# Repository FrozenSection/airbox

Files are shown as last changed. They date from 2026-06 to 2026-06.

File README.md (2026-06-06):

# AirBox

A small, self-contained indoor **environmental monitor** built on an Adafruit
QT Py ESP32-S3. It measures temperature, humidity, barometric pressure, and air
quality, and serves everything from a **local web dashboard** on local WiFi —
no cloud, no app, no Home Assistant required.

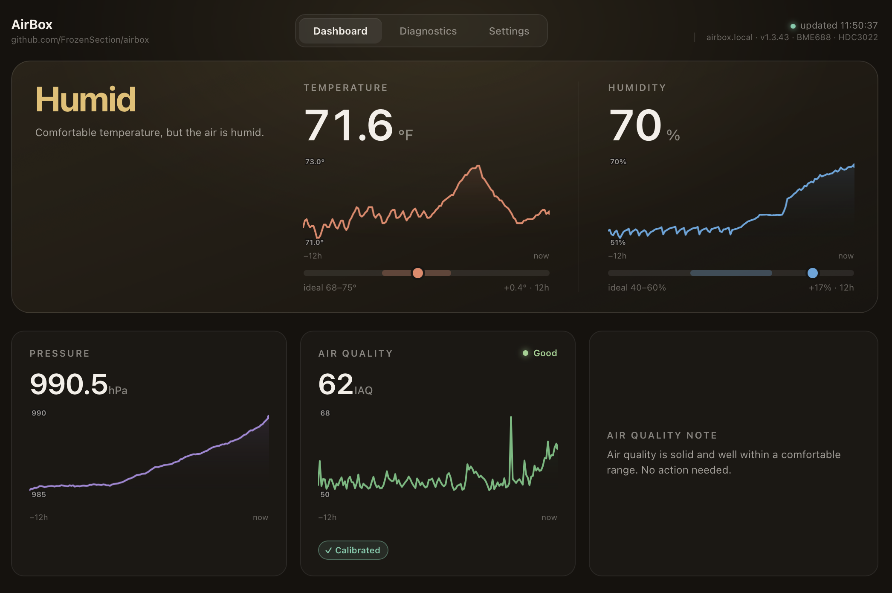
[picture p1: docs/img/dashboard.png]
dashboard placeholder

<!-- Drop a screenshot at docs/img/dashboard.png -->

## What it does

- **Measures:** temperature & humidity (HDC3022), barometric
  pressure and air quality / IAQ (BME688 via Bosch BSEC2).
- **Local dashboard:** live readings + 12 h trend charts at
  `http://airbox.local`, served straight from the device. Works on a network
  with no internet access.
- **Easy WiFi setup:** on first boot it creates a setup hotspot; scan the QR
  code on the OLED with your phone, pick your network, done.
- **Browser firmware updates:** upload new firmware from the dashboard — no
  cable, no IDE.
- **Robust by design:** hardware watchdog, automatic sensor recovery, and
  air-quality calibration that survives reboots and WiFi changes.

## Hardware

- Adafruit QT Py ESP32-S3
- Adafruit HDC3022 precision temperature/humidity sensor (STEMMA QT)
- Adafruit BME688 4-in-1 sensor (STEMMA QT)
- *Optional:* a 128×64 SSD1306 STEMMA QT OLED (enables on-device readout and
  the setup QR code; the device runs fine headless, if desired)

All three boards daisy-chain off the QT Py's STEMMA QT port (the secondary I²C
bus, `Wire1`). See [`hardware/`](hardware/) for the enclosure.

## Getting started

> **Just received a device?** The one-page
> [`docs/quick-start.md`](docs/quick-start.md) gets you from power-on to the
> dashboard in four steps.

1. **Build the firmware** — see [`firmware/README.md`](firmware/README.md) for
   the board settings and library list, then flash over USB-C.
2. **First-time WiFi setup** — [`docs/first-time-setup.md`](docs/first-time-setup.md).
3. **Using the dashboard** — what each reading means and what to trust:
   [`docs/dashboard.md`](docs/dashboard.md).
4. **Changing networks / recovery** — [`docs/recovery.md`](docs/recovery.md).
5. **Terminal / HTTP API** — drive it from `curl` or the USB serial console:
   [`docs/api.md`](docs/api.md).

## Repository layout

```
firmware/   Arduino sketch (airbox.ino, config.h, web_ui.h)
hardware/   3D-printable enclosure files + print notes
docs/        setup, dashboard, and recovery guides
```

## Licenses

- **Firmware & software:** MIT — see [`LICENSE`](LICENSE).
- **3D enclosure files:** Creative Commons Attribution 4.0 (CC BY 4.0) — see
  [`hardware/LICENSE`](hardware/LICENSE).

Contributions and remixes welcome.

## Acknowledgments

For transparency: the firmware, captive-portal provisioning, web dashboard, and documentation were **written by Anthropic's Claude** (via Claude Code), working from the requirements, design decisions, hardware testing, and review provided by the repo owner. The code is AI-written under human direction — not hand-coded by the repo owner.

(Forked from an earlier Home Assistant MQTT sensor and rebuilt as a standalone
device.)

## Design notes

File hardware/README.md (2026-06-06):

# Hardware — enclosure

3D-printable enclosure and mounting files for the standalone AirBox.

## Files

| File | Print? | Purpose |
|---|---|---|
| `enclosure/AirBox_Enclosure.STL` | ✅ ×1 | Main body — the three-chamber enclosure |
| `enclosure/AirBox_Back.STL` | ✅ ×1 | Back cover |
| `enclosure/AirBox.3MF` | — | Both parts arranged in one project file (load this if your slicer prefers it) |
| `enclosure/AirBox.STEP` | — | Editable CAD source, for remixing |

Print `AirBox_Enclosure.STL` **and** `AirBox_Back.STL` (one each). The `.3MF` is
those same two parts bundled together for convenience; the `.STEP` is the
editable source for anyone who wants to modify the design.

## Design notes / requirements

The enclosure needs to accommodate the airflow the air-quality sensor depends
on, and keep the HDC3022 and BME688 away from heat sources:

- **Three separate chambers** to isolate the HDC3022, BME688, and QT Py ESP32/OLED display
- **Vents** in all three chambers for adequate air flow and heat dissipation.
- **OLED cutout** for the 0.96" 128×64 display.
- **USB-C access** for power and recovery flashing.
- **No external BOOT button or pin-hole** — the QT Py's BOOT button (used for the
  physical WiFi reset and for DFU recovery) stays sealed inside, so reaching it
  means **opening the enclosure**. This is fine in normal use: WiFi reset and
  reconfiguration are available from the dashboard (Settings → Reconfigure WiFi),
  and firmware updates happen over the network or USB-C without opening the case.
  See [recovery](../docs/recovery.md).
- Daisy-chained STEMMA QT cables need a little internal slack.

## Print settings

| Setting | Value |
|---|---|
| Material | PETG |
| Layer height | 0.2 mm |
| Infill | Gyroid: 15% |
| Supports | _TBD per part and as needed_ |

## License

Enclosure files are licensed **CC BY 4.0** — see [LICENSE](LICENSE). (The
firmware is MIT; see the repository root.)

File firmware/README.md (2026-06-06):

# Firmware — AirBox

Arduino sketch for the Adafruit QT Py ESP32-S3 standalone environmental
monitor. Reads a BME688 (via Bosch BSEC2) and an HDC3022, serves a local web
dashboard, and provisions WiFi through a captive portal.

## Board

- **Adafruit QT Py ESP32-S3** (No PSRAM or 2MB PSRAM — both work)
- Arduino IDE board: **Tools → Board → ESP32 Arduino → Adafruit QT Py ESP32-S3**
- Install the **esp32 by Espressif Systems** board package (arduino-esp32 v3.x)
- Partition scheme: **REQUIRED → "Minimal SPIFFS (1.9MB APP with OTA/128KB
  SPIFFS)"** (Tools → Partition Scheme). This is mandatory, not optional:
  - The QT Py S3's **default partition has _no_ OTA and no usable filesystem**,
    which would silently break **browser OTA** *and* **persistent history**.
  - "Minimal SPIFFS" provides the two app slots OTA needs **and** a small
    filesystem for the saved trend history.
  - arduino-cli: append it to the FQBN —
    `…:adafruit_qtpy_esp32s3_n4r2:PartitionScheme=min_spiffs`
  - Trade-off: this replaces the TinyUF2 layout, so drag-and-drop `.uf2`
    flashing is unavailable. Flash over USB/serial (or OTA) instead.

## Libraries (Arduino IDE → Library Manager)

| Library | Author | Notes |
|---|---|---|
| Adafruit SSD1306 | Adafruit | OLED (+ Adafruit GFX, Adafruit BusIO pulled in) |
| Adafruit HDC302x | Adafruit | HDC3022 temperature/humidity |
| BSEC2 Software Library | Bosch Sensortec | BME688 air quality (`bsec2`) |
| ArduinoJson | Benoit Blanchon | v7.x |
| **ESP Async WebServer** | **ESP32Async** | the maintained fork — *not* me-no-dev |
| **Async TCP** | **ESP32Async** | matching fork; install explicitly |
| **ElegantOTA** | **Ayush Sharma** | v3.x, browser OTA |
| PubSubClient | Nick O'Leary | only if `ENABLE_MQTT` is set |

> Install the **ESP32Async** versions of ESP Async WebServer / Async TCP. The
> older `me-no-dev` packages are incompatible with arduino-esp32 v3.x. Pin the
> versions once the sketch builds cleanly.

`DNSServer`, `ESPmDNS`, `Update`, `Preferences`, `WiFi`, `Wire`, and the QR
encoder (`qrcode.h`, used for the OLED setup/URL codes) all ship with the ESP32
core — no separate install. (Don't install the ricmoo "QRCode" library — its
header name collides with the core's and would break the build.)

### ElegantOTA async mode — handled automatically

ElegantOTA must be told to use AsyncWebServer. A committed
[`airbox/build_opt.h`](airbox/build_opt.h) injects
`-DELEGANTOTA_USE_ASYNC_WEBSERVER=1` globally, which both Arduino IDE 2.x and
arduino-cli honor — so there's nothing to configure and no library files to
edit. (Verified: compiles clean on esp32:esp32 3.3.8 for the QT Py S3.)

## Build flags (`config.h`)

Everything tunable lives in [`airbox/config.h`](airbox/config.h).
No secrets are stored in committed source — WiFi credentials and optional MQTT
settings are entered in the web UI and saved to NVS; the OTA password lives in a
gitignored `secret.h` (see below).

- `ENABLE_MQTT` (default `0`) — also push to an MQTT broker / Home Assistant.
- `ENABLE_ARDUINO_OTA` (default `0`) — network flashing from the IDE/PlatformIO.
- `ENABLE_NET_OTA` (default `1`) — browser/ElegantOTA flashing. Set `0` for a
  **USB-only** build with no network flash path at all (maximum hardening).

### OTA security

The dashboard is open by design (read-only, trusted-LAN), but **network OTA is
the only remote code-execution path**, so it's locked separately. Copy
[`airbox/secret.h.example`](airbox/secret.h.example) to `airbox/secret.h` (it's
gitignored) and set a strong password:

```c
#define OTA_USERNAME "airbox"
#define OTA_PASSWORD "a-long-random-string"
```

With `secret.h` present, `/update` and the `/ota/*` endpoints require HTTP Basic
Auth — this defeats the realistic threat (an IoT worm scanning the LAN for open
ESP OTA endpoints). Without `secret.h` the build still compiles but OTA is open
and emits a `#warning`. The password is compile-time: to change it, edit
`secret.h`, recompile, and flash once over USB. (It's plain HTTP, so it doesn't
stop an on-path LAN MITM — for that you'd want signed images / Secure Boot, which
is overkill for a one-off gift.)

## First flash

1. Open `airbox/airbox.ino` in Arduino IDE.
2. Select the board + partition scheme above, install the libraries.
3. Upload over USB-C.
4. On first boot the device has no WiFi credentials → it starts the
   **AirBox-Setup** access point. Follow [docs/first-time-setup.md](../docs/first-time-setup.md).

After the first flash, firmware updates can be done entirely in the browser at
`http://<hostname>.local/update` (no cable needed).

## Building an OTA binary

The browser updater at `/update` takes a compiled **app image** (`*.ino.bin`).
Two ways to produce it:

**Arduino IDE 2.x**
1. Select the board **and** Partition Scheme **"Minimal SPIFFS (1.9MB APP with
   OTA/128KB SPIFFS)"** — this is required; a non-OTA scheme produces a binary
   that uploads but won't boot.
2. **Sketch → Export Compiled Binary** (`⌘⌥S`).
3. The binaries land in a `build/<fqbn>/` folder inside the sketch directory.
   Upload **`airbox.ino.bin`** to `/update`.
   - Do *not* use `airbox.ino.merged.bin`, `*.bootloader.bin`, or
     `*.partitions.bin` — those are for a full USB/esptool flash, not OTA.

**arduino-cli**
```sh
arduino-cli compile \
  --fqbn "esp32:esp32:adafruit_qtpy_esp32s3_n4r2:PartitionScheme=min_spiffs" \
  --output-dir build  firmware/airbox
# -> upload build/airbox.ino.bin at http://<hostname>.local/update
```
(Use `…_nopsram` instead of `…_n4r2` for the no-PSRAM board.)

Bump `FW_VERSION` in `config.h` before building so the OLED header / dashboard
confirm the new build actually took after the OTA.

## Notes on the preserved sensor core

The BSEC2 integration, CRC32-wrapped NVS calibration persistence, per-sensor
health/staleness/reinit logic, and the 60 s task watchdog are carried over
unchanged from the Home Assistant version. The watchdog is automatically
extended to 5 minutes during an OTA flash and restored afterward. BSEC
calibration (NVS namespace `bsec`) is **preserved across a WiFi reset** — only
the `cfg` namespace is cleared when you reconfigure WiFi.

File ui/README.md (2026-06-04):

# AirBox dashboard UI (source)

The dashboard the firmware serves at `http://airbox.local` lives here as editable
source, then gets bundled into the firmware.

| File | Role |
|---|---|
| `index.html` | Markup + CSS. Loads the JS via `<script src="airbox-app.js">`. |
| `airbox-app.js` | Dashboard logic (vanilla JS, canvas charts). |
| `build-web-ui.py` | Inlines the JS, **gzip-compresses** the page, and writes the `INDEX_HTML_GZ` byte array into `firmware/airbox/web_ui.h`. |

**This is the single source of truth.** `firmware/airbox/web_ui.h`'s `INDEX_HTML_GZ`
block (a gzip byte array, between the `>>> GENERATED >>>` markers) is a *generated*
artifact — don't hand-edit it; edit the files here and rebuild.

## Edit & preview
Open `index.html` directly in a browser. With no device on the network it falls
back to built-in **mock data**, so you can iterate on layout/logic offline. To
preview against a real device, serve this folder and point the fetches at the
device (or just flash and test on hardware).

## Build into the firmware
```sh
python3 ui/build-web-ui.py      # regenerates firmware/airbox/web_ui.h
```
Standard-library Python only — no packages needed. Then recompile/flash.

Notes:
- `PORTAL_HTML` (the captive-portal page) is hand-written in `web_ui.h` and is
  **not** touched by the bundler.
- The page is gzip-compressed into `INDEX_HTML_GZ` and served **zero-copy** with
  `Content-Encoding: gzip` (the `/` handler streams it straight from flash) — small
  on the wire and no per-request heap copy. The mock-data fallback only kicks in
  for `file://` preview; on the device a failed fetch shows a stale banner, never
  fake data.
- Keep it dependency-free: no CDNs, web fonts, or external libraries — the device
  serves this on a network that may have no internet.

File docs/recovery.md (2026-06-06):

# Changing networks & recovery

This device is designed so you can never paint yourself into a corner — there
are three independent ways back to a working state, from fully software to
fully physical.

## 1. It can't join WiFi (automatic)

If the saved network is gone, renamed, or has a new password, the device tries
to connect for ~30 seconds at boot and then **automatically falls back to the
`AirBox-Setup` portal**. Just redo [first-time setup](first-time-setup.md).
You don't have to do anything to trigger this.

## 2. Reconfigure from the dashboard

If want to move it to a different network:

1. Open `http://airbox.local` → **Settings** tab.
2. Tap **Reconfigure WiFi** and confirm.
3. The device reboots into the `AirBox-Setup` portal — rejoin it and pick the
   new network.

## 3. Physical reset — hold BOOT (requires opening the enclosure)

A last resort if the dashboard is unreachable *and* the device won't fall back
to the portal on its own. The BOOT button is **inside the enclosure** (no
external button or pin-hole), so this one needs you to **open the case first** —
no trouble with a couple of screws/clips, just not a no-tools step. Once it's
open:

1. With the device powered and running, **press and hold the BOOT button for
   about 3 seconds.**
2. It wipes the saved WiFi credentials and reboots into the `AirBox-Setup`
   portal.

> Press BOOT **after** the device has booted — don't hold it during power-up
> (holding it at reset puts the ESP32-S3 into USB flashing mode instead, which
> is a different thing).
>
> In practice you'll rarely get here: methods 1 and 2 above need no tools, and
> cover almost every "can't reach it" case. Reach for BOOT only when both fail.

## What is *not* erased

A WiFi reset (any of the above) clears **only the network credentials**. These
are preserved:

- The **air-quality (BSEC) calibration** — so you don't lose the 24–48 h of
  learning every time you change networks.
- Your **device name**, **temperature unit**, and **hostname** settings.

## Full wipe (start completely fresh)

To also clear the air-quality calibration, use **Settings → Recalibrate air
sensor** on the dashboard. IAQ accuracy drops to 0 and re-learns over 24–48 h.

## Updating firmware

- **Browser (normal):** Settings → **Firmware update**, or go to
  `http://airbox.local/update`. The updater asks for a login (the firmware
  update is the one password-protected action on the device); enter the
  credentials provided with the unit, then upload the new `.bin`. The device
  reboots automatically.
- **USB:** re-flash from the Arduino IDE over USB-C any time (no login needed).

If an update is ever interrupted (power loss mid-flash), the device's bootloader
keeps the previous working firmware on its other partition; power-cycle and
retry, or re-flash over USB. A normal USB re-flash needs no button presses; only
a fully unresponsive board would need manual DFU mode (hold the internal BOOT
button at power-up), which means opening the enclosure.

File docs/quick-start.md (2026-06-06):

# AirBox — Quick Start

<!--
  Regenerate the printable PDF after editing this file:

      python3 -m venv /tmp/rlvenv && /tmp/rlvenv/bin/pip install -q reportlab
      /tmp/rlvenv/bin/python docs/make-quickstart-pdf.py   # run from repo root

  NOTE: the PDF text is hardcoded in make-quickstart-pdf.py, NOT read from this
  markdown — if you change wording here, mirror it in that script too.
-->

> 🖨️ **Printable one-pager:** [`AirBox-Quick-Start.pdf`](AirBox-Quick-Start.pdf)
> (includes a scan-to-open QR for this repo). Regenerate with
> [`make-quickstart-pdf.py`](make-quickstart-pdf.py).

A standalone indoor air & environment monitor. **No app, account, or cloud** —
it serves its own dashboard on your local network.

**You'll need:** USB-C power, and a **2.4 GHz** WiFi network (name + password).

---

## 1. Power it on
Plug in USB-C. The little screen shows **WiFi Setup**, the network name
**`AirBox-Setup`**, and a **QR code**.

## 2. Join the device
On your phone, **point the camera at the QR code** → tap to join the
**`AirBox-Setup`** WiFi (it's open, no password). A setup page opens
automatically. *(If it doesn't, open a browser to `http://192.168.4.1`.)*

## 3. Hand it your WiFi
Pick your network from the list, enter its password, tap **Connect**. The device
reboots and joins your WiFi. The screen then shows its address.

## 4. Open the dashboard
On any device on the **same WiFi**, browse to:

> ## http://airbox.local

*(If `.local` doesn't resolve on your network, use the IP address shown on the
device's screen.)*

---

## Reading it
Four live tiles — **Temperature, Humidity, Pressure, Air Quality (IAQ)** — each
with a 12-hour trend chart.
- **IAQ** is a 0–500 index (lower = cleaner). It needs **24–48 h** of run time to
  self-calibrate; "calibration" climbs from 0 to 3 on the Diagnostics tab.
- **Diagnostics** tab: sensor health, network info, system stats, and a
  **Download CSV** button (last 7 days of data).
- **Settings** tab: device name, °F/°C, time zone, screen brightness & night
  mode.

## Good to know
- **Firmware updates** happen in the browser at **`http://airbox.local/update`**.
  It'll ask for a login — that's the one password-protected action on the device;
  use the update credentials provided with the unit.
- The screen dims/sleeps on a schedule if you enable **Night Mode**; the
  dashboard always works even when the screen is off.

## If something seems off
- **Can't reach `airbox.local`** → use the **IP address** shown on the screen.
- **Changing WiFi / moved it to a new network** → on the dashboard,
  **Settings → Reconfigure WiFi**, or hold the internal **BOOT** button for ~3 s
  to return to the setup screen. (Your air-quality calibration is preserved.)
- **Screen shows `STALE`** → a momentary sensor hiccup; it self-recovers, or just
  power-cycle it.

---

**Full guide, data details & source code:**
[github.com/FrozenSection/airbox](https://github.com/FrozenSection/airbox)

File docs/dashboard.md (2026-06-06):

# Using the dashboard

Open `http://airbox.local` on any device on the same WiFi network. The page has
three tabs: **Dashboard**, **Diagnostics**, **Settings**.

## Dashboard tab

### Comfort verdict
At the top, a plain-language **verdict** summarizes the room from the temperature
and humidity against your **Comfort targets** (set in Settings) — e.g.
*Comfortable, Cool, Warm, Dry, Humid, Cold & dry, Warm & humid…* — with a
one-line suggestion (e.g. "the air is dry — a humidifier would help"). The page's
accent tint shifts with it. It's an interpretation layered on top of the numbers;
the raw readings are always shown below.

### The four readings
Each with a 12-hour trend chart:

| Reading | Source | Notes |
|---|---|---|
| **Temperature** | HDC3022 | Primary, lab-grade (±0.1 °C). Shown in your chosen °F/°C. |
| **Humidity** | HDC3022 | Primary (±0.5 % RH). |
| **Pressure** | BME688 | Barometric pressure (hPa). Good for spotting weather trends. |
| **Air Quality (IAQ)** | BME688 + BSEC2 | 0 = excellent … 500 = very poor. See calibration note below. |

The **Temperature** and **Humidity** tiles also show a **range bar** marking where
the current value sits within your ideal band (`ideal X–Y`).

Charts show the most recent **~12 hours** (a sample every 5 minutes) with a time
axis (`-Xh … now`) and **min/max scale labels** so you can read the actual range
at a glance. History is saved to flash, so it **survives a reboot** and keeps up
to **7 days** for CSV export (Diagnostics tab).

> **A note on sudden steps in the trend.** Each chart point is a snapshot taken
> every 5 minutes, so a *fast* real-world change — opening a window, cooking, a
> shower in the next room — can appear as a steep, near-vertical step at the right
> edge rather than a smooth curve. That's expected: the chart is a 5-minute-
> resolution **trend**, and it simply has no in-between points to draw a fast
> event with. The big numbers at the top of each tile are the live reading (they
> update every few seconds); the chart will catch up and smooth out as the next
> few samples come in. Nothing is wrong with the sensor.

## Diagnostics tab

The raw/secondary values and device health, grouped by subsystem:

- **Sensors** — each sensor's status (OK/fault), seconds since its last good
  reading, and the BME688's **calibration** state (0–3).
- **Air quality detail** — **raw BME688 temperature / humidity** (these read a
  bit high because the gas heater warms the chip — trust the HDC3022 on the
  Dashboard for ambient T/RH), plus **eCO₂ / bVOC**, which are BSEC2 *estimates*
  from the same gas signal as IAQ (they track IAQ rather than adding independent
  info).
- **Network** — IP address, hostname, WiFi SSID, signal strength (RSSI).
- **System** — firmware version, uptime, free heap, and **last reset reason**
  (Power-on / Brownout / Task WDT / Software / Panic — handy for diagnosing an
  unexpected restart).
- **Export data (CSV)** — **Download CSV** grabs the last 7 days at 5-minute
  spacing (timestamp, temperature, humidity, pressure, IAQ).

## Settings tab

Grouped into sections:

- **Device** — Device Name (header / OLED / browser title), Temperature Unit
  (°F/°C), mDNS Hostname (the `.local` address; applies after restart), and
  **Time Zone** (a named zone — DST is handled automatically; used for
  timestamps and the night-mode clock, synced over NTP).
- **Comfort targets** — the ideal **temperature** and **humidity** bands that
  drive the verdict and range bars, entered in your chosen unit. Applies on save.
- **Display** — **Brightness** (Low / Medium / High / Max OLED contrast; lower
  meaningfully extends panel life, default Medium) and **Night Mode** (between
  the hours you set, the OLED either **blanks** or **dims** — your choice; the
  sub-options grey out when it's off). The dashboard and sensors keep running
  even while the screen is dark.
- **Maintenance** — Firmware update (browser OTA), Recalibrate air sensor
  (clears the BSEC baseline → IAQ accuracy 0), Reconfigure WiFi, Restart (the
  last two: see [recovery.md](recovery.md)).

## About IAQ calibration

The **calibration** indicator (Diagnostics tab) climbs from *unreliable* → *low*
→ *medium* → *high* over the first 24–48 hours as BSEC2 learns your environment's
baseline. Until it reaches *medium/high*, treat IAQ as a relative trend rather
than an absolute number. The learned calibration is saved to flash and restored
on reboot, so this only happens once (unless you recalibrate).

## Air-quality reference

The IAQ tile shows the **descriptor** for the current level (with a green→red dot)
and the **Air quality note** card explains it and suggests what to do. The bands
are Bosch's BSEC IAQ classification:

| IAQ | Descriptor |
|---|---|
| 0–50 | Excellent |
| 51–100 | Good |
| 101–150 | Lightly polluted |
| 151–200 | Moderately polluted |
| 201–250 | Heavily polluted |
| 251–350 | Severely polluted |
| 351–500 | Extremely polluted |

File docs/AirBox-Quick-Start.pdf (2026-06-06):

# AirBox

## Quick Start

A standalone indoor air & environment monitor. No app, account, or cloud - it serves its own dashboard on your local network.

Scan for the full
guide & source

Set it up
1 Power it on. Plug in USB-C. The screen shows WiFi Setup, the network AirBox-Setup, and a QR code.
2 Join the device. On your phone, scan that QR to join the AirBox-Setup WiFi (open, no password). A setup page opens automatically. (If not, browse to http://192.168.4.1.)
3 Hand it your WiFi. Pick your 2.4 GHz network, enter its password, tap Connect. The device reboots and joins.
4 Open the dashboard. On any device on the same WiFi, go to http://airbox.local (or the IP shown on the screen).

Reading the dashboard
Four live tiles - Temperature, Humidity, Pressure, Air Quality (IAQ) - each with a 12-hour trend. IAQ is a 0 to 500 index (lower = cleaner) and needs 24-48 h to self-calibrate. The Diagnostics tab has sensor health, network info, and a Download CSV button (last 7 days). The Settings tab covers name, units, time zone, screen brightness / night mode.

Good to know
- Firmware updates happen in the browser at http://airbox.local/update (it asks for the update login provided with your unit).
- Enable Night Mode to blank or dim the screen on a schedule; the dashboard still works while the screen is off.

If something seems off
- Can't reach airbox.local - use the IP address shown on the device screen.
- Changing WiFi / moving it - Settings > Reconfigure WiFi, or hold the internal BOOT button ~3 s. (Air-quality calibration is preserved.)
- Screen shows STALE - a momentary sensor hiccup; it self-recovers, or power-cycle it.

Full guide, data details & source code: github.com/FrozenSection/airbox

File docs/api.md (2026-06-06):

# Terminal / HTTP API

AirBox has no login shell — it's a microcontroller — but it exposes a clean HTTP
API over WiFi plus a USB serial console. Everything the dashboard does, you can do
from a terminal with `curl`.

The data and control API is **unauthenticated by design** — a trusted-LAN
environmental monitor. Anyone on the same WiFi can read it and use the
maintenance actions (restart, recalibrate, etc.). The **one exception is OTA
firmware update**, which requires a password (see below) — it's the only path
that can change the running code, so it's locked even though the rest is open.

mDNS resolves `airbox.local`, but the resolver lags a few seconds — for scripting,
use the device's raw IP (shown on the OLED, or read `.ip` from `/api/data`).

---

## 1. Over WiFi — `curl` against the HTTP API

### Read live telemetry (JSON)

```bash
curl -s http://airbox.local/api/data | jq
```

This is the same payload the dashboard polls. Key fields:

| Field | Meaning |
|---|---|
| `temp`, `rh` | Temperature (in the configured unit) and humidity % — HDC3022 |
| `pressure` | Barometric pressure (hPa) — BME688 |
| `iaq`, `iaq_acc` | Air-quality index (0–500) and BSEC accuracy (0–3) |
| `eco2`, `bvoc` | Estimated CO₂ (ppm) and breath-VOC (ppm) — BME688 |
| `bme_temp`, `bme_rh` | BME688's own temp/RH (secondary; HDC3022 is primary) |
| `hdc_ok`, `bme_ok` | Per-sensor health flags |
| `rssi`, `ssid`, `chan` | WiFi signal (dBm), network, channel |
| `mac`, `bssid`, `ip` | Device MAC (for a DHCP reservation), connected AP/mesh node, IP |
| `uptime` | Seconds since boot |
| `heap`, `heap_min`, `heap_largest` | Free / min-ever / largest-contiguous internal RAM (bytes) |
| `psram_free` | Free PSRAM (bytes) |
| `chip_temp` | ESP32-S3 die temperature (°C) — runs warm, ~50–70 °C is normal |
| `reset_reason` | Why it last rebooted |
| `fw` | Firmware version (confirms an OTA took) |

Pull one field:

```bash
curl -s http://airbox.local/api/data | jq '.chip_temp, .rssi'
```

### Watch it live (1 Hz)

```bash
while true; do curl -s http://airbox.local/api/data \
  | jq -c '{t:.temp, rh, iaq, chip:.chip_temp, rssi}'; sleep 1; done
```

### History

```bash
curl -s http://airbox.local/api/history      | jq   # JSON, the 12 h chart window
curl -s http://airbox.local/api/history.csv  -o airbox-history.csv  # full 7 days, streamed
```

### Actions (POST)

State-changing requests require the header **`X-AirBox: 1`** (a lightweight
CSRF guard — a malicious web page can't set a custom header on a cross-origin
request, so it can't trigger these). GET/read endpoints don't need it.

```bash
H='-H X-AirBox:1'
curl $H -X POST http://airbox.local/api/restart                          # reboot
curl $H -X POST http://airbox.local/api/recalibrate                      # kick BSEC recalibration
curl $H -X POST http://airbox.local/api/clear-history                    # wipe trend log only
curl $H -X POST http://airbox.local/api/factory-reset -d 'wifi=1&calib=1'
```

For `factory-reset`, each flag is optional and defaults off (`0` = keep):
- `wifi=1`  — also forget the WiFi credentials (forces re-provisioning)
- `calib=1` — also discard the BSEC calibration state

### Change settings (POST, form-encoded)

```bash
curl -H 'X-AirBox: 1' -X POST http://airbox.local/api/settings \
  -d 'name=AirBox&unit=F&hostname=airbox&brightness=64&tz=1&night_en=0'
```

Accepted fields (send only what you're changing):

`name`, `unit` (`F`/`C`), `hostname`, `brightness` (0–255), `night_en` (0/1),
`night_start`, `night_end` (minutes-of-day), `night_mode` (0=blank, 1=dim),
`tz` (timezone index), `comfort_tmin`, `comfort_tmax`, `comfort_hmin`,
`comfort_hmax`, `comfort_unit`.

Changes take effect on the next firmware loop (a flag is set; the loop applies it).

### Firmware update (OTA)

Unlike the rest of the API, **OTA requires authentication** — it's the only
endpoint that can change the firmware, so it's protected by HTTP Basic Auth
(credentials set at build time in `firmware/airbox/secret.h`). The browser
updater at `http://airbox.local/update` will prompt for them.

Scripted (ElegantOTA's two-step flow; `$OTA_USER`/`$OTA_PASS` are your
`secret.h` credentials):

```bash
IP=airbox.local; BIN=airbox.ino.bin
MD5=$(md5 -q "$BIN")                                    # Linux: md5sum
curl -u "$OTA_USER:$OTA_PASS" "http://$IP/ota/start?mode=fr&hash=$MD5"
curl -u "$OTA_USER:$OTA_PASS" -F "file=@$BIN;filename=airbox.ino.bin" \
     "http://$IP/ota/upload"                            # device reboots on success
```

(If the firmware was built with `ENABLE_NET_OTA 0`, there is no network flash
path at all — updates are USB-only.)

### Endpoint summary

| Method | Path | Purpose |
|---|---|---|
| GET  | `/` | Dashboard (gzipped HTML) |
| GET  | `/favicon.ico` | Tab icon |
| GET  | `/api/data` | Live telemetry (JSON) |
| GET  | `/api/history` | 12 h chart window (JSON) |
| GET  | `/api/history.csv` | Full 7-day history (CSV, chunked) |
| POST | `/api/settings` | Update configuration |
| POST | `/api/restart` | Reboot |
| POST | `/api/recalibrate` | Kick BSEC recalibration |
| POST | `/api/reconfigure` | Re-run first-time setup logic |
| POST | `/api/clear-history` | Wipe the trend log |
| POST | `/api/factory-reset` | Reset config (optional `wifi`/`calib` flags) |
| GET/POST | `/update`, `/ota/*` | ElegantOTA firmware upload — **auth required** |

All `POST /api/*` endpoints require the `X-AirBox: 1` header (CSRF guard); `/ota/*`
requires HTTP Basic Auth. GET endpoints are open.

A handy alias for daily use:

```bash
alias airbox='curl -s http://airbox.local/api/data | jq'
```

---

## 2. Over USB — serial console

For boot logs, the WiFi-join sequence, sensor init, and low-level diagnostics —
especially useful when WiFi won't come up and the HTTP API is unreachable.

Plug in the QT Py and open the console at **115200 baud**:

```bash
ls /dev/cu.usb*                              # find the port
screen /dev/cu.usbmodemXXXX 115200           # or: minicom -b 115200 -D <port>
```

Exit `screen` with `Ctrl-A` then `K`.

---

See also: [dashboard.md](dashboard.md) for the web UI, and
[recovery.md](recovery.md) for stuck-device procedures.

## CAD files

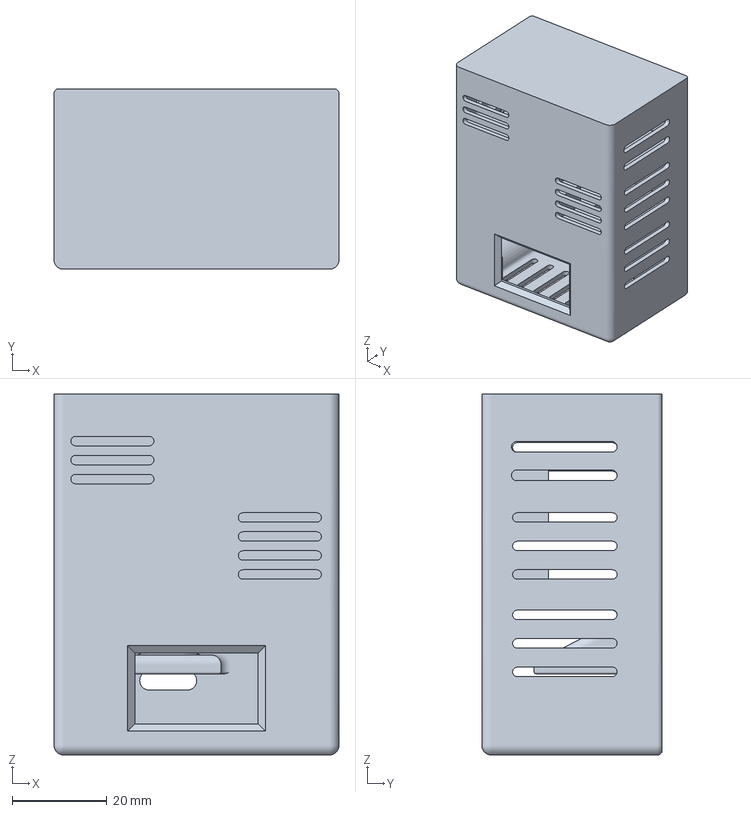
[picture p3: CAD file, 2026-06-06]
hardware/enclosure/AirBox.3MF
60.0 x 38.0 x 76.0 mm

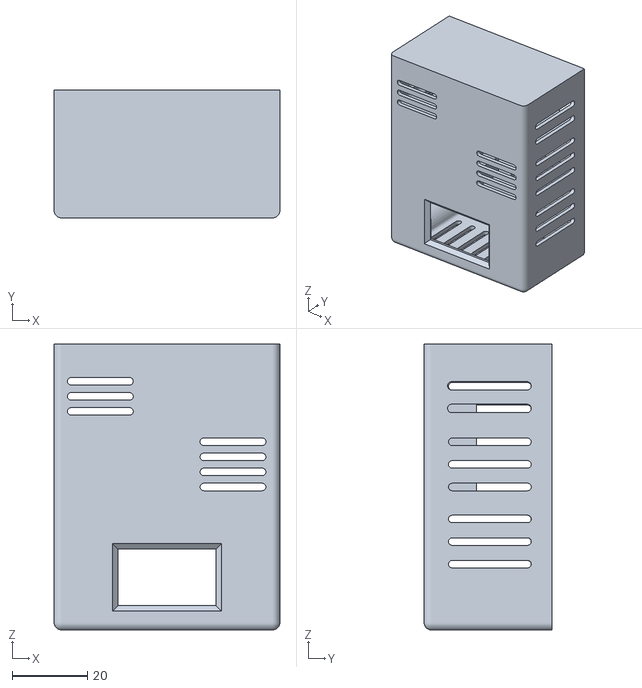
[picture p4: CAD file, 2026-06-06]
hardware/enclosure/AirBox_Enclosure.STL
60.0 x 34.0 x 76.0

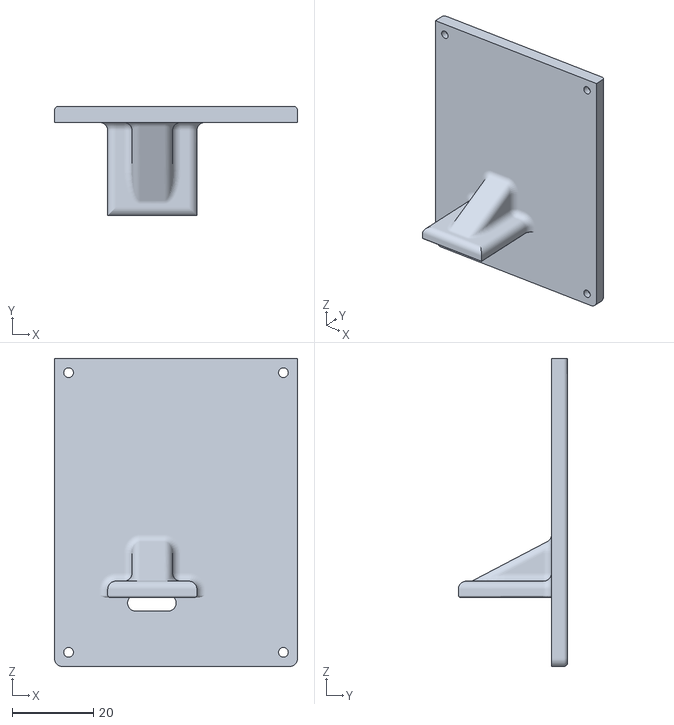
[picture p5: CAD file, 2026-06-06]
hardware/enclosure/AirBox_Back.STL
60.0 x 27.0 x 76.0

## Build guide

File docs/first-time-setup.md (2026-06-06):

# First-time setup

When the device has no saved WiFi network (fresh flash, or after a WiFi reset)
it starts a temporary setup hotspot so you can tell it which network to join.

## The quick way (with the OLED)

1. **Power the device.** After a few seconds the OLED shows **"WiFi Setup"**,
   the hotspot name **`AirBox-Setup`**, and a **QR code**.
2. **Point your phone camera at the QR code.** It offers to join the
   `AirBox-Setup` network — tap to join. 
3. Your phone should **automatically pop up the setup page**. If it doesn't,
   open a browser to **`http://192.168.4.1`**.
4. **Pick your home WiFi** from the list, type its password, tap **Connect**.
5. The device reboots and joins your network. The OLED then shows
   **"Connected!"** with the dashboard address.

## The manual way (no OLED, or QR won't scan)

1. On your phone or laptop, open WiFi settings and join the network
   **`AirBox-Setup`**.
2. A captive-portal page should appear automatically. If not, browse to
   **`http://192.168.4.1`**.
3. Select your network, enter the password, **Connect**.

## After setup

- Open the dashboard at **`http://airbox.local`** (or use the IP address your router assigned).
- Go to the **Settings** tab and:
  - set a **device name** (e.g. "Office", "Nursery" if desired),
  - choose **°F or °C**.

> **Air-quality calibration:** the IAQ reading starts at accuracy 0 and
> self-calibrates over the first **24–48 hours** of normal use. This is expected;
> see [dashboard.md](dashboard.md).

## Acceptance checklist

- [ ] Fresh boot shows the `AirBox-Setup` hotspot (and QR on the OLED).
- [ ] Phone scans the QR, joins, and the setup page appears automatically.
- [ ] Network list populates; selecting your WiFi and submitting reboots the
      device onto your network.
- [ ] `http://airbox.local` loads the dashboard; live values update.
- [ ] Trend charts begin filling in (first points appear after a few minutes).
- [ ] °F/°C toggle and device name persist across a reboot.
- [ ] Browser OTA at `/update` prompts for the update login, then flashes a new
      build, after which the device reboots on the new firmware.
- [ ] Holding **BOOT** for ~3 s returns the device to the setup portal, and the
      IAQ calibration is still intact afterward.

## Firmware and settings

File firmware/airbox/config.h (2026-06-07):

// config.h — build-time defaults and feature flags for AirBox.
//
// IMPORTANT: nothing secret lives here. WiFi credentials, the admin/OTA
// password, and (optional) MQTT credentials are all entered through the
// device's web UI at runtime and stored in NVS. This file only holds
// non-secret defaults and compile-time switches, so it is safe to commit
// to a public repository.

#ifndef CONFIG_H
#define CONFIG_H

// ----- Firmware identity -----
// Bump on every change we flash, so the OLED header / dashboard confirm which
// build is actually running (handy for verifying an OTA took).
#define FW_VERSION        "1.4.0"
#define DEVICE_MODEL      "QT Py ESP32-S3 + BME688 + HDC3022 (standalone)"

// ----- Feature flags -----
// MQTT / Home Assistant discovery. OFF by default — this is a standalone
// device. Set to 1 only if you later want to also push to an MQTT broker;
// broker host/user/pass are then entered in the web Settings page.
#define ENABLE_MQTT          0

// ArduinoOTA (network flashing from the Arduino IDE / PlatformIO / espota).
// OFF by default — browser-based OTA (ElegantOTA at /update) is the primary
// update path for a standalone gift. Turn on if you flash from a dev setup.
#define ENABLE_ARDUINO_OTA   0

// Network OTA master switch. 1 = browser/ElegantOTA flashing is available
// (default); 0 = USB-only, NO network flash path at all — the maximum-hardening
// build with zero remote code-execution surface. When enabled, OTA is protected
// by HTTP Basic Auth *if* firmware/airbox/secret.h defines OTA_USERNAME/
// OTA_PASSWORD (copy secret.h.example). Without secret.h the build still compiles
// but OTA is open and a #warning is emitted at compile time.
#define ENABLE_NET_OTA       1

// ----- Captive-portal / AP defaults -----
// Setup access point is intentionally OPEN (no password) so the OLED join-QR
// stays small enough to render crisply on the 0.96" screen, and so first-time
// setup is one scan-and-tap. The AP only ever serves the provisioning page.
#define AP_SSID           "AirBox-Setup"
#define AP_IP_STR         "192.168.4.1"

// ----- Runtime config defaults (overridable in the web Settings page) -----
#define DEFAULT_DEVICE_NAME  "AirBox"
#define DEFAULT_HOSTNAME     "airbox"        // -> http://airbox.local
#define DEFAULT_TEMP_UNIT    'F'             // 'F' or 'C'
// No admin password: the web UI (dashboard, settings, OTA at /update) is open on
// the local network by design — a trusted-LAN environmental monitor. OTA and USB
// flashing both stay available; OTA is just unauthenticated now.

// ----- Comfort targets (dashboard verdict + range bars) -----
// Stored in °C (canonical, like all temps); the web UI edits in the display
// unit and the firmware converts. Humidity is unit-agnostic %.
#define DEFAULT_COMFORT_TMIN_C  20.0f   // 68 °F
#define DEFAULT_COMFORT_TMAX_C  24.4f   // 76 °F
#define DEFAULT_COMFORT_HMIN    40
#define DEFAULT_COMFORT_HMAX    60

// ----- OLED longevity (all overridable in the web Settings page) -----
// SSD1306 contrast 0-255. Lower current = longer OLED life; the UI exposes
// Low/Medium/High/Max. A moderate default is gentler than the panel's ~0xCF.
#define DEFAULT_BRIGHTNESS   64
// Night mode: between these local hours, either fully blank the screen (saves
// the most life, keeps a bedroom dark) or just dim it. Off by default; needs
// the UTC offset for the clock.
#define DEFAULT_NIGHT_ENABLE 0
#define DEFAULT_NIGHT_START  23              // hour 0-23, local
#define DEFAULT_NIGHT_END    7
#define DEFAULT_NIGHT_MODE   0               // 0 = blank (screen off), 1 = dim
#define NIGHT_DIM_CONTRAST   4               // SSD1306 contrast used in dim mode (very low)
// Timezone is chosen from a named list (see TZ_TABLE in airbox.ino); stored as
// an index. DST is handled automatically via the POSIX TZ rule.
// 0 = UTC, 1 = Eastern (US). Default Eastern for a US-bound gift.
#define DEFAULT_TZ_INDEX     1
#define NTP_SERVER           "pool.ntp.org"
// Anti-burn-in: nudge the whole layout a few px on this cycle so static labels
// never sit on the same pixels forever.
#define PIXEL_SHIFT_INTERVAL_MS  300000UL    // 5 minutes

// ----- Trend history ring buffer -----
// Fixed 7 days at 5-minute spacing (2016 points ≈ 40 KB). Persisted to LittleFS
// so it survives a reboot, with a UTC timestamp per sample. Requires a partition
// scheme WITH a filesystem AND OTA — "Minimal SPIFFS (1.9MB APP with OTA/128KB
// SPIFFS)" (see firmware/README). The dashboard chart shows the most recent
// CHART_SAMPLES (12 h); the CSV export covers the whole 7 days.
#define HISTORY_SAMPLES          2016        // 7 days @ 5 min
#define HISTORY_INTERVAL_MS      300000UL    // 5 minutes
#define CHART_SAMPLES            144         // dashboard chart window: last 12 h (full day/night cycle)
#define HISTORY_SAVE_INTERVAL_MS 1800000UL   // flush history to flash every 30 min
#define HISTORY_FILE             "/hist.bin"

// ----- Pins / hardware -----
#define I2C_SDA_PIN       41                 // STEMMA QT (Wire1)
#define I2C_SCL_PIN       40
#define BOOT_BUTTON_PIN   0                  // QT Py BOOT button (read post-boot only)

// ----- Watchdog -----
#define WATCHDOG_TIMEOUT_MS    60000UL       // 60 s; extended to 5 min during OTA flash
#define OTA_WATCHDOG_MS        300000UL      // 5 min

// ----- Factory-reset hold -----
#define FACTORY_RESET_HOLD_MS  3000UL        // hold BOOT this long (in run/portal) to wipe WiFi

#endif // CONFIG_H

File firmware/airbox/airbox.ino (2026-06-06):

// AirBox — QT Py ESP32-S3 + BME688 (BSEC2) + HDC3022 + optional SSD1306
//
// A STANDALONE indoor environmental monitor. No Home Assistant required:
//   * WiFi is provisioned through a captive portal (OLED shows a join-QR).
//   * Data is served from a local web dashboard (live values + trend charts).
//   * Firmware updates happen in the browser (ElegantOTA at /update).
//   * mDNS publishes the dashboard at http://<hostname>.local
//
// Forked from the Home Assistant MQTT version. The hardened sensor core
// (BSEC2 + CRC32 NVS calibration, HDC3022 read path, per-sensor health /
// staleness / reinit, 60 s task watchdog) is preserved as-is. MQTT/HA
// discovery is retained behind ENABLE_MQTT (config.h), OFF by default.
//
// Recovery paths (see docs/recovery.md):
//   1. Auto-fallback to the setup portal if WiFi won't connect at boot.
//   2. Hold the BOOT button ~3 s (any time) to wipe WiFi and re-provision.
//   3. "Reconfigure WiFi" button on the dashboard.
// Calibration (NVS "bsec") is preserved across a WiFi reset.

#include "config.h"

#include <Wire.h>
#include <Adafruit_GFX.h>
#include <Adafruit_SSD1306.h>
#include <bsec2.h>
#include <Adafruit_HDC302x.h>
#include <WiFi.h>
#include <DNSServer.h>
#include <ESPmDNS.h>
#include <ArduinoJson.h>
#include <Preferences.h>
#include <esp_mac.h>
#include <esp_task_wdt.h>
#include <esp_system.h>  // esp_reset_reason()
#include <esp_heap_caps.h>  // heap_caps_get_largest_free_block() — fragmentation diag
#include <time.h>
#include <LittleFS.h>    // persistent trend history
#include "qrcode.h"  // QR encoder bundled in the ESP32 core (espressif__qrcode)

#define ELEGANTOTA_USE_ASYNC_WEBSERVER 1
#include <ESPAsyncWebServer.h>
#include <ElegantOTA.h>

#include "web_ui.h"
#include "favicon_png.h"

// Optional OTA credentials. secret.h is gitignored (see secret.h.example). If it
// defines OTA_USERNAME/OTA_PASSWORD, network OTA is protected by HTTP Basic Auth;
// if absent, OTA is open and setupElegantOTA() emits a compile-time #warning.
#if __has_include("secret.h")
  #include "secret.h"
#endif

#if ENABLE_MQTT
#include <PubSubClient.h>
#endif
#if ENABLE_ARDUINO_OTA
#include <ArduinoOTA.h>
#endif

// =================== OLED (optional) ===================
#define SCREEN_WIDTH 128
#define SCREEN_HEIGHT 64
#define OLED_RESET -1
Adafruit_SSD1306 display(SCREEN_WIDTH, SCREEN_HEIGHT, &Wire1, OLED_RESET);
bool displayOK = false;

// =================== Sensors ===================
Bsec2 envSensor;
Adafruit_HDC302x hdc;
bool bmeOK = false;
bool hdcOK = false;

const bsecSensor bsecSubscriptionList[] = {
  BSEC_OUTPUT_STATIC_IAQ,
  BSEC_OUTPUT_CO2_EQUIVALENT,
  BSEC_OUTPUT_BREATH_VOC_EQUIVALENT,
  BSEC_OUTPUT_SENSOR_HEAT_COMPENSATED_TEMPERATURE,
  BSEC_OUTPUT_RAW_TEMPERATURE,
  BSEC_OUTPUT_RAW_HUMIDITY,
  BSEC_OUTPUT_RAW_PRESSURE,
};
const uint8_t bsecSubscriptionCount =
  sizeof(bsecSubscriptionList) / sizeof(bsecSubscriptionList[0]);

Preferences bsecPrefs;
uint8_t bsecStateBlob[BSEC_MAX_STATE_BLOB_SIZE];
bool bsecStateSavedOnce = false;

struct SensorData {
  float hdcTempC, hdcRH;
  float bmeTempC, bmeRH, bmePresHpa;
  float bmeIaq, bmeEco2, bmeBvoc, bmeCompTempC;
  uint8_t bmeIaqAccuracy;
  bool hdcValid;
  bool bmeValid;
  unsigned long hdcLastGoodMs;
  unsigned long bmeLastGoodMs;
  uint16_t hdcFailStreak;
  uint16_t bmeFailStreak;
  uint32_t hdcTotalFails;
  uint32_t bmeTotalFails;
};
SensorData latest = {0, 0, 0, 0, 0, 0, 0, 0, 0, 0, false, false, 0, 0, 0, 0, 0, 0};

// Cadences
const unsigned long READ_INTERVAL_DISPLAY_MS = 3000;
const unsigned long READ_INTERVAL_HEADLESS_MS = 10000;
const unsigned long SENSOR_REINIT_INTERVAL_MS = 300000;
const unsigned long BSEC_STATE_SAVE_INTERVAL_MS = 3UL * 3600UL * 1000UL;
const unsigned long WIFI_FORCE_RECONNECT_MS = 300000;
const unsigned long MAX_VALUE_AGE_MS = 300000;
const uint16_t MAX_FAIL_STREAK = 20;

unsigned long lastRead = 0;
unsigned long lastBmeReinit = 0;
unsigned long lastHdcReinit = 0;
unsigned long lastWifiReconnect = 0;
unsigned long lastBsecStateSave = 0;
unsigned long lastHistMs = 0;

// =================== Trend history ring buffer ===================
// Static allocation (link-time accounted, no heap fragmentation). Stores raw
// values; temperature is converted to the display unit when served.
float    histT[HISTORY_SAMPLES];    // °C (raw)
float    histRH[HISTORY_SAMPLES];   // %
float    histP[HISTORY_SAMPLES];    // hPa
float    histIAQ[HISTORY_SAMPLES];  // IAQ
uint32_t histTime[HISTORY_SAMPLES]; // UTC epoch seconds (0 = before clock sync)
int histHead = 0;
int histCount = 0;
bool fsOK = false;                  // LittleFS mounted
unsigned long lastHistSave = 0;

// =================== Timezones ===================
// Named zones -> POSIX TZ rule (DST handled automatically). cfg.tzIndex stores
// the position. KEEP THIS IN SYNC with the <select id="sTz"> options in web_ui.h.
struct TzZone { const char* label; const char* posix; };
const TzZone TZ_TABLE[] = {
  {"UTC",                    "UTC0"},
  {"Eastern (New York)",     "EST5EDT,M3.2.0,M11.1.0"},
  {"Central (Chicago)",      "CST6CDT,M3.2.0,M11.1.0"},
  {"Mountain (Denver)",      "MST7MDT,M3.2.0,M11.1.0"},
  {"Arizona (no DST)",       "MST7"},
  {"Pacific (Los Angeles)",  "PST8PDT,M3.2.0,M11.1.0"},
  {"Alaska (Anchorage)",     "AKST9AKDT,M3.2.0,M11.1.0"},
  {"Hawaii (no DST)",        "HST10"},
  {"UK (London)",            "GMT0BST,M3.5.0/1,M10.5.0"},
  {"Central Europe",         "CET-1CEST,M3.5.0,M10.5.0/3"},
  {"India (Kolkata)",        "IST-5:30"},
  {"Japan (Tokyo)",          "JST-9"},
  {"Sydney",                 "AEST-10AEDT,M10.1.0,M4.1.0/3"},
};
const uint8_t TZ_COUNT = sizeof(TZ_TABLE) / sizeof(TZ_TABLE[0]);

// =================== Runtime config (NVS "cfg") ===================
struct Config {
  String ssid;
  String pass;
  String devName;
  String hostname;
  char   unit;  // 'C' or 'F'
  uint8_t brightness;   // SSD1306 contrast 0-255
  bool    nightEn;      // blank/dim the OLED on a schedule
  uint16_t nightStartMin;  // minutes-of-day 0-1439 (local)
  uint16_t nightEndMin;
  uint8_t nightMode;    // 0 = blank (off), 1 = dim
  uint8_t tzIndex;      // index into TZ_TABLE (DST-aware local time)
  float   comfortTminC, comfortTmaxC;   // comfort band, °C canonical
  uint8_t comfortHmin,  comfortHmax;    // comfort band, %
#if ENABLE_MQTT
  String mqttHost;
  String mqttUser;
  String mqttPass;
#endif
};
Config cfg;
Preferences cfgPrefs;

// =================== Web / network ===================
AsyncWebServer server(80);
DNSServer dnsServer;
String deviceId;     // qtpy_xxxxxx (from MAC)
IPAddress apIP(192, 168, 4, 1);

enum Mode { MODE_PORTAL, MODE_RUN };
Mode mode = MODE_RUN;

// Cross-task action flags. Web handlers run on the AsyncTCP task and MUST NOT
// block (no I2C / NVS / restart). They only set these flags; loop() performs
// the work on the main task.
volatile bool pendingSaveWifi = false;
volatile bool pendingSaveSettings = false;
volatile bool pendingRestart = false;
volatile bool pendingReconfigure = false;
volatile bool pendingRecalibrate = false;
volatile bool pendingWifiReset = false;   // BOOT-button WiFi wipe -> setup portal (same as Reconfigure WiFi)
volatile bool pendingClearHistory = false;   // wipe the trend ring buffer (no reboot)
volatile bool pendingFullReset = false;      // settings -> defaults (+ optional WiFi/calib), reboot
volatile bool frWifi = false, frCalib = false;

// Staging buffers for the above (written in handlers, read in loop()).
String stgSsid, stgWifiPass;
String stgName, stgUnit, stgHost;
String stgBright, stgNight, stgNStart, stgNEnd, stgNMode, stgTz;
String stgCtmin, stgCtmax, stgChmin, stgChmax, stgCunit;
#if ENABLE_MQTT
String stgMqttHost, stgMqttUser, stgMqttPass;
#endif

// =================== MQTT (optional) ===================
#if ENABLE_MQTT
WiFiClient wifiClient;
PubSubClient mqtt(wifiClient);
String haDeviceName, roomSlug, stateTopic, availTopic;
const char* DISCOVERY_PREFIX = "homeassistant";
const uint16_t MQTT_PORT = 1883;
unsigned long lastPublish = 0;
unsigned long lastMqttAttempt = 0;
const unsigned long PUBLISH_INTERVAL_MS = 30000;
const unsigned long MQTT_RETRY_MS = 5000;
#endif

static inline bool inRange(float v, float lo, float hi) {
  return !isnan(v) && !isinf(v) && v >= lo && v <= hi;
}
static inline float toUnit(float c) {
  return (cfg.unit == 'F') ? (c * 9.0f / 5.0f + 32.0f) : c;
}

// =================== Watchdog helpers ===================
void wdtReconfigure(uint32_t ms) {
  esp_task_wdt_config_t c = {.timeout_ms = ms, .idle_core_mask = 0, .trigger_panic = true};
  esp_task_wdt_reconfigure(&c);
}

// =================== Config store ===================
void loadConfig() {
  cfgPrefs.begin("cfg", true);  // read-only
  cfg.ssid      = cfgPrefs.getString("ssid", "");
  cfg.pass      = cfgPrefs.getString("pass", "");
  cfg.devName   = cfgPrefs.getString("name", DEFAULT_DEVICE_NAME);
  cfg.hostname  = cfgPrefs.getString("host", DEFAULT_HOSTNAME);
  cfg.unit      = cfgPrefs.getString("unit", String(DEFAULT_TEMP_UNIT))[0];
  cfg.brightness = cfgPrefs.getUChar("bright", DEFAULT_BRIGHTNESS);
  cfg.nightEn    = cfgPrefs.getBool("nightEn", DEFAULT_NIGHT_ENABLE);
  // Night window is stored as minutes-of-day. Migrate from the legacy hour keys
  // (nStart/nEnd) if the minute keys aren't present yet.
  cfg.nightStartMin = cfgPrefs.getUShort("nsm", (uint16_t)cfgPrefs.getUChar("nStart", DEFAULT_NIGHT_START) * 60);
  cfg.nightEndMin   = cfgPrefs.getUShort("nem", (uint16_t)cfgPrefs.getUChar("nEnd", DEFAULT_NIGHT_END) * 60);
  cfg.nightMode  = cfgPrefs.getUChar("nMode", DEFAULT_NIGHT_MODE);
  cfg.tzIndex = cfgPrefs.getUChar("tz", DEFAULT_TZ_INDEX);
  if (cfg.tzIndex >= TZ_COUNT) cfg.tzIndex = DEFAULT_TZ_INDEX;
  cfg.comfortTminC = cfgPrefs.getFloat("ctmin", DEFAULT_COMFORT_TMIN_C);
  cfg.comfortTmaxC = cfgPrefs.getFloat("ctmax", DEFAULT_COMFORT_TMAX_C);
  cfg.comfortHmin  = cfgPrefs.getUChar("chmin", DEFAULT_COMFORT_HMIN);
  cfg.comfortHmax  = cfgPrefs.getUChar("chmax", DEFAULT_COMFORT_HMAX);
#if ENABLE_MQTT
  cfg.mqttHost  = cfgPrefs.getString("mhost", "");
  cfg.mqttUser  = cfgPrefs.getString("muser", "");
  cfg.mqttPass  = cfgPrefs.getString("mpass", "");
#endif
  cfgPrefs.end();
  if (cfg.unit != 'C' && cfg.unit != 'F') cfg.unit = DEFAULT_TEMP_UNIT;
}

void saveWifiCreds(const String& ssid, const String& pass) {
  cfgPrefs.begin("cfg", false);
  cfgPrefs.putString("ssid", ssid);
  cfgPrefs.putString("pass", pass);
  cfgPrefs.end();
}

// Clears ONLY the WiFi credentials — device name, unit, and the "bsec"
// calibration namespace are preserved across a WiFi reset.
void clearWifiCreds() {
  cfgPrefs.begin("cfg", false);
  cfgPrefs.remove("ssid");
  cfgPrefs.remove("pass");
  cfgPrefs.end();
}

void setContrast(uint8_t v);     // defined with the OLED rendering helpers

// Apply the selected timezone so localtime_r() returns DST-correct local time,
// and (re)start the NTP sync.
void applyTimezone() {
  uint8_t i = (cfg.tzIndex < TZ_COUNT) ? cfg.tzIndex : 0;
  configTzTime(TZ_TABLE[i].posix, NTP_SERVER);
}

void applyAndSaveSettings() {
  if (stgName.length()) cfg.devName = stgName.substring(0, 32);
  if (stgUnit.length()) cfg.unit = stgUnit[0];
  if (stgHost.length()) {
    // Keep the mDNS hostname DNS-safe: lowercase [a-z0-9-], max 32 chars. Strips
    // anything else (spaces, punctuation, markup) rather than persisting garbage.
    String h = stgHost; h.toLowerCase(); String clean;
    for (size_t i = 0; i < h.length() && clean.length() < 32; i++) {
      char ch = h[i];
      if ((ch >= 'a' && ch <= 'z') || (ch >= '0' && ch <= '9') || ch == '-') clean += ch;
    }
    if (clean.length()) cfg.hostname = clean;
  }
  if (cfg.unit != 'C' && cfg.unit != 'F') cfg.unit = DEFAULT_TEMP_UNIT;
  if (stgBright.length()) cfg.brightness = (uint8_t)constrain(stgBright.toInt(), 0, 255);
  if (stgNight.length())  cfg.nightEn = (stgNight.toInt() != 0);
  if (stgNStart.length()) cfg.nightStartMin = (uint16_t)constrain(stgNStart.toInt(), 0, 1439);
  if (stgNEnd.length())   cfg.nightEndMin = (uint16_t)constrain(stgNEnd.toInt(), 0, 1439);
  if (stgNMode.length())  cfg.nightMode = (stgNMode.toInt() != 0) ? 1 : 0;
  if (stgTz.length()) {
    uint8_t t = (uint8_t)stgTz.toInt();
    cfg.tzIndex = (t < TZ_COUNT) ? t : 0;
  }
  // Comfort targets — temp bands arrive in comfort_unit; store canonical °C.
  if (stgCtmin.length()) cfg.comfortTminC = (stgCunit == "F") ? (stgCtmin.toFloat() - 32.0f) * 5.0f / 9.0f : stgCtmin.toFloat();
  if (stgCtmax.length()) cfg.comfortTmaxC = (stgCunit == "F") ? (stgCtmax.toFloat() - 32.0f) * 5.0f / 9.0f : stgCtmax.toFloat();
  if (stgChmin.length()) cfg.comfortHmin = (uint8_t)constrain(stgChmin.toInt(), 0, 100);
  if (stgChmax.length()) cfg.comfortHmax = (uint8_t)constrain(stgChmax.toInt(), 0, 100);
  // Sanity-clamp comfort temps to a sane indoor band (canonical °C) and ensure
  // min <= max, so a typo or an inverted/garbage range can't persist.
  cfg.comfortTminC = constrain(cfg.comfortTminC, 0.0f, 45.0f);
  cfg.comfortTmaxC = constrain(cfg.comfortTmaxC, 0.0f, 45.0f);
  if (cfg.comfortTminC > cfg.comfortTmaxC) { float t = cfg.comfortTminC; cfg.comfortTminC = cfg.comfortTmaxC; cfg.comfortTmaxC = t; }
  if (cfg.comfortHmin > cfg.comfortHmax) { uint8_t t = cfg.comfortHmin; cfg.comfortHmin = cfg.comfortHmax; cfg.comfortHmax = t; }
  cfgPrefs.begin("cfg", false);
  cfgPrefs.putString("name", cfg.devName);
  cfgPrefs.putString("unit", String(cfg.unit));
  cfgPrefs.putString("host", cfg.hostname);
  cfgPrefs.putUChar("bright", cfg.brightness);
  cfgPrefs.putBool("nightEn", cfg.nightEn);
  cfgPrefs.putUShort("nsm", cfg.nightStartMin);
  cfgPrefs.putUShort("nem", cfg.nightEndMin);
  cfgPrefs.putUChar("nMode", cfg.nightMode);
  cfgPrefs.putUChar("tz", cfg.tzIndex);
  cfgPrefs.putFloat("ctmin", cfg.comfortTminC);
  cfgPrefs.putFloat("ctmax", cfg.comfortTmaxC);
  cfgPrefs.putUChar("chmin", cfg.comfortHmin);
  cfgPrefs.putUChar("chmax", cfg.comfortHmax);
#if ENABLE_MQTT
  if (stgMqttHost.length()) cfg.mqttHost = stgMqttHost;
  if (stgMqttUser.length()) cfg.mqttUser = stgMqttUser;
  if (stgMqttPass.length()) cfg.mqttPass = stgMqttPass;
  cfgPrefs.putString("mhost", cfg.mqttHost);
  cfgPrefs.putString("muser", cfg.mqttUser);
  cfgPrefs.putString("mpass", cfg.mqttPass);
#endif
  cfgPrefs.end();
  // Apply the display + clock changes live (we're in loop() context).
  if (displayOK) setContrast(cfg.brightness);
  applyTimezone();
  Serial.println("Settings saved");
}

// =================== BSEC callback + NVS state (preserved) ===================
void bsecDataCallback(bme68x_data /*data*/, bsecOutputs outputs, Bsec2 /*bsec*/) {
  if (!outputs.nOutputs) return;
  for (uint8_t i = 0; i < outputs.nOutputs; i++) {
    const bsecData out = outputs.output[i];
    switch (out.sensor_id) {
      case BSEC_OUTPUT_STATIC_IAQ:
        latest.bmeIaq = out.signal;
        latest.bmeIaqAccuracy = out.accuracy;
        break;
      case BSEC_OUTPUT_CO2_EQUIVALENT:
        latest.bmeEco2 = out.signal;
        break;
      case BSEC_OUTPUT_BREATH_VOC_EQUIVALENT:
        latest.bmeBvoc = out.signal;
        break;
      case BSEC_OUTPUT_SENSOR_HEAT_COMPENSATED_TEMPERATURE:
        if (inRange(out.signal, -40.0f, 85.0f)) latest.bmeCompTempC = out.signal;
        break;
      case BSEC_OUTPUT_RAW_TEMPERATURE:
        if (inRange(out.signal, -40.0f, 85.0f)) latest.bmeTempC = out.signal;
        break;
      case BSEC_OUTPUT_RAW_HUMIDITY:
        if (inRange(out.signal, 0.0f, 100.0f)) latest.bmeRH = out.signal;
        break;
      case BSEC_OUTPUT_RAW_PRESSURE:
        if (inRange(out.signal, 800.0f, 1100.0f)) latest.bmePresHpa = out.signal;
        break;
      default:
        break;
    }
  }
  latest.bmeValid = true;
  latest.bmeLastGoodMs = millis();
  latest.bmeFailStreak = 0;
}

void logBsecStatus(const char* context) {
  Serial.printf("  %s — BSEC status=%d, BME68x status=%d\n",
                context, (int)envSensor.status, (int)envSensor.sensor.status);
}

static uint32_t bsecCrc32(const uint8_t* data, size_t len) {
  uint32_t crc = 0xFFFFFFFF;
  for (size_t i = 0; i < len; i++) {
    crc ^= data[i];
    for (uint8_t k = 0; k < 8; k++) crc = (crc >> 1) ^ (0xEDB88320 & -(crc & 1));
  }
  return ~crc;
}
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
void loop() {
  esp_task_wdt_reset();
#if ENABLE_NET_OTA
  ElegantOTA.loop();
#endif
  checkBootButton();
  handlePendingActions();

  if (mode == MODE_PORTAL) {
    dnsServer.processNextRequest();
    static unsigned long lastPortalDraw = 0;
    if (millis() - lastPortalDraw > 5000) { lastPortalDraw = millis(); showPortalScreen(); }
    return;
  }

  // ---- MODE_RUN ----
#if ENABLE_ARDUINO_OTA && ENABLE_NET_OTA
  ArduinoOTA.handle();
#endif

  if (bmeOK) {
    if (!envSensor.run()) {
      bool realError = ((int)envSensor.status < 0) || ((int)envSensor.sensor.status < 0);
      if (realError) {
        latest.bmeFailStreak++;
        latest.bmeTotalFails++;
        Serial.printf("BSEC run failed (streak=%u, total=%lu)\n",
                      latest.bmeFailStreak, (unsigned long)latest.bmeTotalFails);
        logBsecStatus("run");
      }
    }
  }

  // WiFi: trust auto-reconnect; force a full cycle if down too long.
  if (WiFi.status() != WL_CONNECTED) {
    if (millis() - lastWifiReconnect > WIFI_FORCE_RECONNECT_MS) {
      lastWifiReconnect = millis();
      Serial.println("WiFi still down — forcing reconnect");
      WiFi.disconnect();
      WiFi.begin(cfg.ssid.c_str(), cfg.pass.c_str());
    }
  } else {
    lastWifiReconnect = millis();
  }

#if ENABLE_MQTT
  if (!mqtt.connected() && millis() - lastMqttAttempt > MQTT_RETRY_MS) {
    lastMqttAttempt = millis();
    if (WiFi.status() == WL_CONNECTED) tryConnectMQTT();
  }
  if (mqtt.connected()) mqtt.loop();
#endif

  unsigned long now = millis();

  // Per-sensor staleness (preserved).
  bool hdcJustWentStale = false, bmeJustWentStale = false;
  if (hdcOK && latest.hdcValid && (now - latest.hdcLastGoodMs > MAX_VALUE_AGE_MS)) {
    Serial.println("HDC stale — marking offline");
    hdcOK = false; latest.hdcValid = false; hdcJustWentStale = true;
  }
  if (bmeOK && latest.bmeValid && (now - latest.bmeLastGoodMs > MAX_VALUE_AGE_MS)) {
    Serial.println("BME stale — marking offline");
    bmeOK = false; latest.bmeValid = false; bmeJustWentStale = true;
  }
  if (hdcOK && latest.hdcFailStreak > MAX_FAIL_STREAK) {
    Serial.printf("HDC failed %u reads — forcing reinit\n", latest.hdcFailStreak);
    hdcOK = false; latest.hdcValid = false; latest.hdcFailStreak = 0; hdcJustWentStale = true;
  }
  if (bmeOK && latest.bmeFailStreak > MAX_FAIL_STREAK) {
    Serial.printf("BME failed %u reads — forcing reinit\n", latest.bmeFailStreak);
    bmeOK = false; latest.bmeValid = false; latest.bmeFailStreak = 0; bmeJustWentStale = true;
  }
  bool hdcDue = (!hdcOK && (hdcJustWentStale || (now - lastHdcReinit >= SENSOR_REINIT_INTERVAL_MS)));
  bool bmeDue = (!bmeOK && (bmeJustWentStale || (now - lastBmeReinit >= SENSOR_REINIT_INTERVAL_MS)));
  if (hdcDue || bmeDue) recoverI2C();  // clear a wedged bus before re-init
  if (hdcDue) { lastHdcReinit = now; reinitHdc(); }
  if (bmeDue) { lastBmeReinit = now; reinitBme(); }

  // OLED care: night blank/dim + anti-burn-in pixel-shift.
  if (displayOK) {
    bool night = isNightNow();
    bool wasPowered = displayPowered;
    // BLANK mode powers the panel off; DIM mode keeps it on at low contrast.
    setDisplayPower(!(night && cfg.nightMode == 0));
    setContrast((night && cfg.nightMode == 1) ? NIGHT_DIM_CONTRAST : cfg.brightness);
    if (displayPowered && !wasPowered) updateRunDisplay();  // redraw on wake
    if (displayPowered && now - lastShift >= PIXEL_SHIFT_INTERVAL_MS) {
      lastShift = now;
      updateShift();
    }
  }

  unsigned long readInterval = displayOK ? READ_INTERVAL_DISPLAY_MS : READ_INTERVAL_HEADLESS_MS;
  if (now - lastRead >= readInterval) {
    lastRead = now;
    readSensors();
    updateRunDisplay();
  }

  if (now - lastHistMs >= HISTORY_INTERVAL_MS) {
    lastHistMs = now;
    recordHistory();
  }

  // Flush history to flash on a slow cadence (planned restarts flush too).
  if (fsOK && now - lastHistSave >= HISTORY_SAVE_INTERVAL_MS) {
    lastHistSave = now;
    saveHistory();
  }

#if ENABLE_MQTT
  if (now - lastPublish >= PUBLISH_INTERVAL_MS && mqtt.connected()) {
    lastPublish = now;
    publishState();
  }
#endif

  // Persist BSEC calibration once accuracy >= 1 (preserved).
  if (bmeOK && latest.bmeIaqAccuracy >= 1) {
    bool firstSave = !bsecStateSavedOnce;
    bool cadenceDue = (now - lastBsecStateSave >= BSEC_STATE_SAVE_INTERVAL_MS);
    if (firstSave || cadenceDue) {
      lastBsecStateSave = now;
      bsecStateSavedOnce = true;
      saveBsecState();
    }
  }

  // Yield the CPU briefly so the loop core can idle (WFI) between ticks instead
  // of spinning at 100%. Big steady-state heat/power cut on an always-on board;
  // the async web server runs in its own task and is unaffected, and BSEC LP
  // (3 s cadence) and the WDT (60 s) are nowhere near starved at ~100 loops/s.
  delay(10);
}

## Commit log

2026-05-29 Initial commit — standalone env-monitor (captive WiFi + local web dashboard)
    Fork of the Home Assistant env-monitor for a standalone, HA-free device.
    - Captive WiFi portal (open setup AP, OLED join-QR, network scan, reboot-to-apply)
    - Three recovery paths: auto-fallback AP, BOOT-hold WiFi wipe, dashboard reconfigure
    - Local async web dashboard: live readings, 24h trend charts, diagnostics tab,
    limited settings (name, F/C, hostname, admin password)
    - Browser OTA via ElegantOTA (password-gated, watchdog extended during flash)
    - mDNS (http://envmon.local)
    - WiFi creds + settings in NVS "cfg"; BSEC calibration ("bsec") preserved on reset
    - MQTT/HA discovery retained behind ENABLE_MQTT (off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
    [config.h, env-monitor-standalone.ino]
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2026-05-29 OLED longevity: brightness, pixel-shift jitter, NTP night-blanking
    All web-configurable from the Settings tab and persisted in NVS "cfg":
    - Display brightness (SSD1306 contrast) — Low/Medium/High/Max, default Medium;
    lower drive current is the biggest lever on panel life. Applied at boot and
    live on save.
    - Pixel-shift anti-burn-in: the run screen layout walks a small 0-2px offset
    every 5 min so static labels/divider/footer never sit on fixed pixels.
    - Night mode: blank the OLED (DISPLAYOFF) between configurable local hours via
    an NTP clock (UTC offset setting). Off by default; sensors + dashboard keep
    running while the screen is dark, and it redraws immediately on wake.
    config.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
    [airbox.ino, config.h]
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2026-05-29 Fix build: use core QR encoder, add ElegantOTA async build flag
    Verified compiling with arduino-cli (esp32:esp32 3.3.8, QT Py S3 nopsram):
    default build 59% flash / 27% RAM; MQTT+ArduinoOTA path also compiles.
    - QR: the ricmoo "QRCode" lib's qrcode.h collides with the header the ESP32
    core already bundles (espressif__qrcode, used by WiFiProv), so <qrcode.h>
    resolved to the core's. Switched drawQR() to the core's callback-based
    esp_qrcode_generate() API and dropped the external library dependency.
    - ElegantOTA: a sketch #define can't reach the library's own .cpp, so async
    mode wasn't taking. Added committed build_opt.h with
    -DELEGANTOTA_USE_ASYNC_WEBSERVER=1 (honored by Arduino IDE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
    [airbox.ino]
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2026-05-31 OLED: cleaner layout + last-reset-reason diagnostic
    Port the more readable run-screen layout from the HA env-monitor sibling:
    two divider rules / three zones, header with device name + firmware version +
    filled/hollow WiFi status dot, right-aligned (anchored) humidity, and stable
    placeholders before the first read. Char buffers avoid heap churn on redraw;
    8-point pixel-shift orbit, 2px inset so it never clips. IAQ stays numeric
    (value + accuracy) — no qualitative band, by design.
    Add esp_reset_reason() as a "Last reset" diagnostic (Power-on / Brownout /
    Task WDT / Software / Panic) on the dashboard Diagnostics tab — helps tell a
    power issue from a hang.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
    [airbox.ino]
2026-05-31 UI: right-align OLED QR codes; add Discard-changes button
    - Setup/portal + connect splash QR codes are now right-aligned (hug the right
    edge, adapting to the QR's actual size) so the left side is always free for
    text — fixes the SSID text running into the QR. Portal text lines tightened;
    splash IP moved below the QR so a long address can't collide.
    - Settings tab gains a "Discard changes" button that re-pulls the device's
    saved values into the form, throwing away unsaved edits (nothing was written),
    so you can back out cleanly without remembering the previous state.
    [airbox.ino]
2026-05-31 Persistent history (LittleFS) + CSV export; require OTA partition
    Critical: the QT Py S3 default partition (tinyuf2_noota) has no OTA slot and no
    filesystem — browser OTA and history persistence both need it. Build now
    requires "Minimal SPIFFS (1.9MB APP with OTA/128KB SPIFFS)"
    (PartitionScheme=min_spiffs). Verified compiling/flashing at 66% of the 1.9MB
    app slot.
    - Trend history persists to LittleFS (/hist.bin): saved every 30 min and before
    any planned restart, restored on boot — charts survive reboot/power-cycle.
    - Each sample now carries a UTC timestamp (from NTP) for the CSV.
    - New GET /api/history.csv: all data by default, optional ?from=&to= (UTC epoch)
    date range; timestamps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
    [airbox.ino, config.h]
2026-05-31 v1.1.0: selectable history window (24h/1wk/1mo/1yr); start versioning
    - Fixed 720-point history buffer; sample spacing = chosen window / 720, so
    storage/RAM/payload are bounded regardless of window (can't run out of space).
    Settings dropdown: 24h / 1 week / 1 month / 1 year. Changing it clears past
    data and refills at the new cadence (timestamps make this clean).
    - CSV export simplified to "Download CSV" (the retained window); the /api/
    history.csv from/to params remain for power users.
    - Bump FW_VERSION 1.0.0 -> 1.1.0. From here, bump on every flashed change so the
    OLED header / dashboard confirm which build is running (verifies an OTA took).
    Built but intentionally NOT USB-flash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
    [airbox.ino, config.h]
2026-05-31 v1.2.0: 7-day CSV + fixed 24h chart + timezone picker
    - History is now a fixed 7-day buffer at 5-min spacing (2016 pts). The dashboard
    chart shows the most recent 24h (CHART_SAMPLES); the CSV exports the full 7
    days. Removes the v1.1.0 retention-window setting and the derived-interval
    machinery — both are now fixed.
    - CSV download is explicit: button "Download CSV (7 days)", filename
    airbox-history-7d.csv; dropped the from/to range params.
    - Replace the raw UTC-offset field with a named-timezone dropdown (TZ_TABLE,
    POSIX rules) — DST handled automatically via configTzTime(). Keep the HTML
    <select> in sync with TZ_TABLE order.
    - Bump 1.1.0 -> 1.2.0. Built for OTA; not USB-flas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
    [airbox.ino, config.h]
2026-05-31 v1.2.1: bigger 2-line OLED + stale alert, I2C recovery, graph legibility, EST default
    - OLED redesigned for legibility: two large (size-2) rows — temperature+humidity,
    then pressure+IAQ (big numbers, small hPa/IAQ labels). Accuracy moved to the
    web UI only. On a sensor stall the line shows "--", the status dot goes hollow,
    and the header shows "STALE" — visible on-device without opening the dashboard.
    - I2C bus recovery (recoverI2C): clocks SCL to free a wedged SDA + STOP, then
    re-inits Wire1. Runs on boot and before each sensor reinit, so a soft reboot
    (e.g. OTA) that leaves the bus stuck can self-heal.
    - Graph legibility: charts no longer zoom tighter than a per-metric minimu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
    [airbox.ino, config.h]
2026-05-31 v1.2.2: chart time axis (span-aware, sparse-friendly)
    Each trend chart gets an x-axis: "-<span> ... now" in the bottom corners. Points
    still fill the full width; the left label shows the ACTUAL span of data present
    (e.g. -15m early on, growing to -24h once full), so it reads correctly without
    looking empty while the buffer populates. Value min/max labels stay on the left.
    [config.h]
2026-05-31 v1.2.3: settings redesign, adaptive IAQ label, drop post-connect QR
    - Settings tab reorganized into labeled cards (Device / Display / Security /
    MQTT / Save / Maintenance). Night Mode capitalized; its behavior + hours are
    now an indented, left-bordered sub-block that greys out and disables when the
    checkbox is off. Timezone moved under Device.
    - OLED: IAQ label is adaptive — "IAQ" normally, "AQ" when the row is tight
    (4-digit pressure + 3-digit IAQ), dropped only if even that won't fit — so it
    can never collide with "hPa". Font is monospace, so this is digit-count based.
    - Post-connect splash no longer shows the dashboard QR (WiFi is already set on a
    reboot/OTA); the QR stays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
    [airbox.ino, config.h]
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2026-05-31 v1.2.4: fix hidden-tab charts, group Diagnostics, settings label polish
    - Fix charts not rendering when returning to the Dashboard tab: a 60s redraw
    firing while the tab was hidden drew the canvases at 0x0. Now draw() bails on a
    zero-size canvas, and switching to the Dashboard tab forces a redraw.
    - Diagnostics reorganized into subsystem cards an EE can scan: Sensors (status +
    age + BME calibration), Air quality detail (raw BME T/RH, eCO2, bVOC), Network
    (IP, hostname, SSID, RSSI), System (firmware, uptime, heap, last reset). Added
    IP + SSID to /api/data.
    - Settings labels to Title Case (Device Name, Temperature Unit, mDNS Hostname,
    Time Zone, Admin Password); night-mode hours re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
    [airbox.ino, config.h]
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2026-06-01 v1.3.0: new Ambient dashboard + comfort targets; UI source + bundler
    New web dashboard (the "Ambient" redesign): self-contained (no CDN/fonts/libs),
    canvas charts with area fill, comfort verdict + range bars, regrouped
    diagnostics. Same API as before plus user-tunable comfort targets.
    Firmware (additive only): Config gains comfortTminC/TmaxC + comfortHmin/Hmax;
    loadConfig/applyAndSaveSettings persist them (NVS, canonical °C, converted from
    the UI's display unit); /api/settings stages comfort_*; buildDataJson emits a
    "comfort" object in display units. config.h adds DEFAULT_COMFORT_*. OLED is
    unchanged (raw values, no verdict).
    UI workflow: dashboard source now lives in ui/ (index.html + ai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
    [airbox.ino, config.h]
2026-06-01 v1.3.1: right-justify the Air Quality status pill
    The support tiles (Pressure, Air Quality) didn't inherit the flex
    space-between that the metric tiles use, so the IAQ status pill (dot + word)
    sat inline next to the label instead of at the right edge. Add `.scard .top`
    flex rule. Pressure (no pill) is unaffected. Regenerated web_ui.h from ui/.
    [config.h]
2026-06-01 v1.3.2: more chart variability (less aggressive y-axis normalization)
    The minSpan floor + 18% padding were over-flattening real 24h data. Halve the
    minSpans (temp 2->1, humidity 6->3, pressure 4->2, IAQ 25->12) and cut padding
    to 10%, so charts zoom closer to the actual range while keeping a small floor so
    sensor noise isn't amplified into fake swings.
    [config.h]
2026-06-01 v1.3.3: dynamic chart time axis + 5% padding, lower minSpan
    - Restore the dynamic left axis label (regressed in the Ambient redesign, which
    hardcoded "-24h"): it now shows the actual data span (-15m -> -24h as the
    window fills). Tag the 4 left-axis spans .axL; redraw() sets them from
    HIST length x interval.
    - Chart padding 10% -> 5%; minSpans lowered (temp 1->0.7, humidity 3->2,
    pressure 2->1.5, IAQ 12->8) for a bit more variability.
    [config.h]
2026-06-01 v1.3.4: 7-band IAQ descriptors + per-level guidance, whole-number IAQ
    Replace the 4-band pill + single templated note with Bosch's BSEC IAQ
    classification (Excellent / Good / Lightly / Moderately / Heavily / Severely /
    Extremely polluted). The tile pill shows the descriptor with a green->red ramp
    dot; the "Air quality note" card shows level-specific guidance. IAQ reports as a
    whole number (no more 113.2951 in prose). When accuracy is 0 (unreliable) the
    note shows a warming-up message instead of a confident verdict; calibration
    state stays in its own pill. docs/dashboard.md table updated to the 7 bands.
    [config.h]
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2026-06-03 v1.3.7: fix dashboard stall — gzip + zero-copy serve
    The dashboard stalled on load/refresh: the "/" handler served the ~35 KB
    INDEX_HTML via the const-char* overload, which copies the whole page into a
    contiguous heap String per request. On a fragmented heap / weak WiFi link that
    allocation (or its multi-segment transfer) wedged and returned zero bytes,
    while the small /api/* endpoints kept working.
    - Bundler (build-web-ui.py) now gzips the inlined dashboard and emits an
    INDEX_HTML_GZ byte array (35.8 KB -> 12.2 KB) between GENERATED markers,
    instead of the raw INDEX_HTML PROGMEM string.
    - "/" handler serves INDEX_HTML_GZ zero-copy (AsyncProgmemResponse) with
    Content-Encoding: gzip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
    [airbox.ino, config.h]
2026-06-03 v1.3.9: web reliability pass — chunked CSV, honest stale UI, heap diagnostics
    Follow-up hardening after the v1.3.7 dashboard stall fix (second-opinion review).
    - /api/history.csv: serve via beginChunkedResponse instead of AsyncResponseStream.
    The stream grows ONE contiguous heap buffer to hold the whole ~80 KB CSV before
    sending — the same large-allocation failure mode as the old dashboard String.
    Now filled ~1.4 KB at a time (whole rows only), peak RAM = one TCP segment.
    Verified: 35.6 KB / 860 rows in ~0.2 s, 3/3 (was 0 bytes / stalled).
    - Dashboard: never substitute MOCK data on the device. Mock is gated to file://
    preview only; on a failed fetch the UI keeps the last real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
    [airbox.ino, config.h]
2026-06-03 v1.3.10: night-mode settings layout fixes
    - Desktop: add 16px top margin above the "Starts at / Ends at" time row so it no
    longer runs into the "During night hours" dropdown above it.
    - Mobile (iPhone/iPad): .row .field{min-width:0} so the side-by-side native
    <input type=time> pickers can shrink to share the row instead of overflowing
    and clipping the right edge (flex items default to min-width:auto, and iOS time
    inputs have a wide intrinsic min-width).
    - gitignore .claude/ (local preview/launch tooling, not for the public repo).
    [config.h]
2026-06-03 v1.3.11: stack night-mode time pickers on phones
    min-width:0 (v1.3.10) let the side-by-side start/end time pickers shrink, which
    fixed iPad but iPhone still clipped — iOS native <input type=time> has a hard
    minimum rendered width it won't go below. Add a <=560px breakpoint that turns the
    #nightSub time row into a column (align-items:stretch; the row's gap:14px becomes
    the vertical spacing). Tablets keep the side-by-side layout.
    [config.h]
2026-06-03 v1.3.12: keep stacked night-time pickers inside the card on iPhone
    v1.3.11 stacked them via flex-direction:column, but on iOS Safari a column flex
    container sizes its cross-axis (width) from the native <input type=time>'s
    intrinsic width, pushing the fields past the card's right edge. Switch to the
    row's natural direction + existing flex-wrap: #nightSub .row .field{flex-basis:100%}
    makes each field take a full line (so they wrap/stack) while min-width:0 keeps
    them within the card width. gap:14px still spaces the two lines.
    [config.h]
2026-06-04 v1.3.13: fix S3 overheating (modem-sleep + loop delay)
    The dashboard going unresponsive "again" was thermal, not RF placement: the
    ESP32-S3 module ran too hot to touch, which degraded the WiFi PA (RSSI drifting
    to -80) and stalled the web server — hot -> weak RF -> unresponsive, a feedback
    loop. Two of our own settings were the heat source:
    - WiFi.setSleep(false) (added v1.3.7 to cut latency) kept the radio at full power
    continuously. Revert to WiFi.setSleep(true) — modem power-save. The latency it
    was fighting was really the 35 KB page (now 12 KB gzipped) + buffered CSV (now
    chunked), so this costs us little now.
    - loop() ran with no delay, pinning a CPU core at 100%. Add delay(1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
    [airbox.ino, config.h]
2026-06-04 v1.3.14: readable charts — y-axis scale labels + 8h window
    The sparklines auto-normalize to fill their height with no y-axis numbers, so a
    0.3-degree wiggle and a 6-degree swing looked identical — magnitude was invisible
    ("worthless given the lack of scale").
    - chart(): draw the window's actual min (bottom-left) and max (top-left) values
    on each canvas, dim with a dark halo for legibility. Per-metric decimals/suffix
    passed from redraw() (temp 1dp/°, humidity 0dp/%, pressure & IAQ 0dp).
    - Shorten the chart window 24h -> 8h (CHART_SAMPLES 288 -> 96) for more recent
    detail and a lighter /api/history payload. Dynamic x-axis label already adapts;
    the "24h" delta label now derives fr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
    [airbox.ino, config.h]
2026-06-04 v1.3.15: give the trend charts real height (44px -> 116px)
    The charts looked like flatlines because they were literally ~40px tall
    (canvas height="44"/"38") under a 60px value + the ideal bar — no vertical room
    for the line to move, scale labels or not. One-line CSS fix: canvas height 116px.
    ~3x the drawing height; paired with the v1.3.14 min/max labels + 8h window the
    sparklines are actually readable now. Kept the graphs (vs dropping them for CSV):
    the problem was real estate, not the feature.
    Verified on hardware (OTA), still cool (chip_temp 45C).
    [config.h]
2026-06-04 v1.3.16: clean up the chart time-axis label (−7.9h → −8h)
    spanLabel() used toFixed(1) under 10h, so the 96-sample / 7.92h window read
    "−7.9h" (and an exact 2h would read "−2.0h") — looks like a bug. Round to whole
    units: minutes under an hour, rounded hours above, so the full window shows a
    clean "−8h" and the reused delta label reads "· 8h". Kept it terse ("−8h", not
    "8 hrs") to match the "now" on the right.
    [config.h]
2026-06-04 v1.3.17: a touch more chart breathing room
    - Chart y-axis padding 5% -> 8% of the data range (proportional, so it scales
    per-metric and never re-flattens the small-range charts — a fixed unit pad
    would have).
    - Canvas height 116 -> 126px (a small bump, not a leap).
    [config.h]
2026-06-04 v1.3.18: actually fix the night-mode time pickers on mobile
    Root cause of the persistent right-side clipping: the two .field wrappers had an
    inline style="flex:1", which sets flex-basis:0 with inline priority — silently
    overriding every stylesheet stacking rule (1.3.11 column, 1.3.12 flex-basis:100%).
    So on phones they stayed shrunk-to-share and the native <input type=time> (which
    won't go below its intrinsic width on iOS) overflowed the card.
    Fix: move flex:1 into CSS (#nightSub .row .field) so the mobile rule can win, and
    on phones (<=560px) make the row a plain block so each picker takes the full card
    width — same size as the "During night hours" dropdown above. Wide screens keep
    the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
    [config.h]
2026-06-04 v1.3.19: stop iOS time inputs overflowing the card (appearance:none)
    Even stacked full-width, the native <input type=time> clipped on the right: iOS
    renders it at an intrinsic width that ignores width:100%/box-sizing. The <select>
    never had this problem because it already sets appearance:none. Apply the same to
    the time inputs (-webkit-appearance:none; min/max-width) so they size to their
    container; keep the value centered via text-align + ::-webkit-date-and-time-value.
    [config.h]
2026-06-04 v1.3.20: move Save/Discard to the bottom of the settings grid
    They lived at the end of the left column, which is fine on desktop's 2-column
    grid but lands them mid-page once the columns stack into one on mobile. Pulled the
    button row out to a direct grid child that spans both columns (.actions {
    grid-column: 1 / -1 }), so it's the last element on both layouts — consistent and
    no longer stranded between sections on mobile. IDs unchanged, so the JS wiring is
    untouched.
    [config.h]
2026-06-04 v1.3.21: About card — add Display + Enclosure, drop Firmware
    Firmware version is already shown in the header and Diagnostics > System, so it
    was redundant in About. Replace that row with Display (SSD1306 OLED 0.96") and
    Enclosure (PETG). Also removed the now-dead $('aFw') write in loadSettings().
    [config.h]
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2026-06-05 v1.3.24: de-orphan the settings Save/Discard buttons
    The two-column settings grid was lopsided (left: Device + Comfort; right:
    Display + Maintenance + About), so the full-width button row sat stranded in the
    empty space under the short left column.
    - Rebalance: move the short "About this device" card to the left column → left is
    Device/Comfort/About, right is Display/Maintenance (much closer in height).
    - Footer treatment: full-width hairline divider above the action row, buttons
    centered — reads as a deliberate end-of-form footer instead of floating.
    [config.h]
2026-06-05 v1.3.25: sticky "unsaved changes" save bar (discoverability fix)
    Settings apply only on Save, so a Save button parked below the fold meant edits
    could silently never "stick" if the user didn't scroll down. Replace the in-flow
    footer with a bar pinned to the bottom of the screen that slides up the instant
    any field changes (#set gets a .dirty class, driven by the existing dirty flag):
    "Unsaved changes · Discard · Save". It's impossible to miss and reachable from
    any scroll position; the page stays clean when there's nothing to save.
    - setDirty(v) toggles #set.dirty (+ a dirtyN guard so the post-save auto-hide
    doesn't fire if a new edit landed during the 1.8s confirmation window).
    - flash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
    [config.h]
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2026-06-05 v1.3.27: stack Maintenance buttons full-width, reorder
    Now there's room in the column, stack the four maintenance actions vertically
    (.btns.stack: flex-direction:column, full-width, centered) instead of a 2x2 grid,
    and reorder to OTA -> Reconfigure WiFi -> Recalibrate -> Restart.
    [config.h]
2026-06-05 v1.3.28: Maintenance — Clear history + Factory reset, recolored
    New actions + a clearer severity color scheme in the stacked Maintenance card:
    - White (safe): Firmware update, Reconfigure WiFi, Restart (moved up, was red —
    a plain reboot has no downside).
    - Amber (clears recoverable data): Recalibrate, Clear history (new).
    - Red (destructive), isolated below a divider with checkboxes + confirm: Factory
    reset (new).
    Firmware:
    - POST /api/clear-history -> pendingClearHistory: zero the ring buffer
    (histHead/histCount=0) and remove the LittleFS file. No reboot.
    - POST /api/factory-reset (wifi/calib params) -> pendingFullReset: wipe the whole
    "cfg" NVS namespace so all settings rever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
    [airbox.ino, config.h]
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2026-06-05 v1.3.30: fix CSV-box "24 h" text; rename pendingFactoryReset -> pendingWifiReset
    - CSV export note said the chart shows the most recent 24 h; it's 8 h since
    v1.3.14.
    - pendingFactoryReset only wiped WiFi and rebooted to the portal (identical to
    pendingReconfigure) — a misleading name now that there's a real factory reset
    (pendingFullReset). Rename to pendingWifiReset. No behavior change.
    [airbox.ino, config.h]
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2026-06-06 v1.3.32: console logo via base64 data URI (network URL didn't render)
    The lazy /airbox-logo.png route returned 200, but Chrome's console won't paint a
    network-URL background image (async fetch / security) — the logo line came up
    blank. Switch to an inline base64 data URI, which renders synchronously.
    Trade-off: the ~1.6 KB logo (~2.2 KB base64) now rides in the page instead of
    lazy-loading, so the gzipped dashboard goes ~13 -> ~17 KB. Removed the now-unused
    route + logo_png.h. Text wordmark + message unchanged.
    [airbox.ino, config.h]
2026-06-06 v1.3.33: fix dashboard-breaking syntax error from the base64 injection
    v1.3.32's base64 logo was injected with single quotes around the inner url()
    inside a single-quoted JS string — `url('data:...')` closed the string early and
    threw a SyntaxError, which killed the entire dashboard script (page rendered
    static placeholders, no data ever loaded). Inner url() must use double quotes:
    url("data:..."). Lesson: validate generated JS, not just that it serves.
    [config.h]
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
